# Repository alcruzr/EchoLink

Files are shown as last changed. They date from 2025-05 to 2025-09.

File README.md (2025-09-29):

# Overview

The EchoLink is a LoRa device that is able to send off-grid type messages when paired with a bluetooth enabled smartphone. The firmware aspect of the Echolink utilizes Meshtastic, an open source firmware. The hardware aspect of the EchoLink is a custom designed PCB that was created for a small and portable form factor.  A custom designed 3D printed enclosure provides easy access to user buttons/switches while also providing protection to the internal PCB and battery.

overall_cropped

# Specifications
* LoRa Transceiver: Waveshare Core 1262 HF LoRa Module, SX1262 Chip
* LoRa Antenna: SMA
* LoRa Operation Frequency: 915MHz (US)
* MCU: ESP32-S3-WROOM-1-MCN16R8
* Bluetooth v5.0
* USB Connector: USB-Micro B (for programming and power)
* Battery: 3.7V Li-Poly, 1200mAh
* Battery Charger: Input 5V via USB-Micro B. 500mAh Charge rate.
* Screen: 128x64 OLED Module, 
* GPS: Adafruit Industries ULTIMATE GPS MODULE PA1616D - 66 (integrated antenna)

# Firmware

The Echolink uses the Meshtastic open source firmware. The custom variant used for the EchoLink and its hardware is provided. The latest Meshtastic firmware will have to be downloaded from https://github.com/meshtastic/firmware 
The "echolink" variant will have to be copied into the /variants/esp32s3 folder. When compiling the firmware using VSCode, select the "echolink" environment. 

Detailed instructions on how to customize, compile, and upload the Meashtastic firmware can be found on the official Meshtastic website.  https://meshtastic.org/docs/development/firmware/build/

Once the firmware is uploaded to the Echolink and powered ON, please refer to the Meshtastic open source project website for further details and instructions on how to pair and operate with a bluetooth enabled smartphone device.  
https://meshtastic.org/

# Hardware

pcb label_final

The EchoLink is utilizes an ESP32-S3 microcontroller which has integrated wifi and bluetooth connectivity. The small form factor, along with its integrated antenna, also helped minimize the overall size of the EchoLink. The ESP32-S3 was also chosen because of the wide support within the Meshtastic firmware.

The LoRa transceiver comes with an on-board uFL connector. A uFL to SMA connector is used to extend the antenna port from the LoRa module to the top of the case allowing for easy access to the LoRa radio antenna port. 

The GPS module has a dedicated ON/OFF switch to allow for easy toggle of the GPS.

A 3.7V Li-Poly battery is used to supply power to the EchoLink. (NOTE: when selecting battery, make sure to verify polarity of JST connector.)

jst polarity new_final

The power circuit utilizes a linear voltage regulator with a fixed output voltage of 3.3V to power all components. To manage the power path between the battery input and USB-Micro B 5V input, a MOSFET power management circuit was implemented. This approach will allow the Echolink to be powered via the internal battery or external 5V input (for charging or power) automatically. 


There is also an available grove connector which allows for external I2C accessories to be connected.

# Case

The case was designed in Fusion360 and 3D printed using PLA. The simple design of the case allowed for minimal parts and hardware while also allowing access to all user buttons, switches and connections. The case consists of a main body, top cover, and single push button. A single M3x6x5 heat-pressed threaded insert and one M3x20 screw holds the entire case together. If the Grove connector is used, the battery will have to be installed at an angle to avoid interfering with the connector.

NOTE: The current case dimensions and design can only accomodate the 1200mAh 3.7V Li-Poly battery from Adafruit (https://www.adafruit.com/product/258). If using a different battery, please verify that dimensions are similar. 

case-bodyTop_label_final

# Resources

https://www.youtube.com/watch?v=zeSlRvCd6tg

https://meshtastic.org/

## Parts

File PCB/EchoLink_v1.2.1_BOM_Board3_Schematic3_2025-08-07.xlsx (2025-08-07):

No. | Quantity | Designator | Value | Part Number | Footprint | Comment
1 | 1 | BT1 |  |  | BAT-SMD_1042P | 1042P
2 | 1 | C1 | 10uF |  | C1206 | C1206
3 | 1 | C2 | 0.1uF |  | C1206 | C1206
4 | 1 | C3 | 10uF |  | C1206 | C1206
5 | 1 | C4 | 1uF |  | C1206 | C1206
6 | 1 | C6 | 1uF |  | C1206 | C1206
7 | 1 | C7 | 0.1uF |  | C1206 | C1206
8 | 1 | C8 | 0.1uF |  | C1206 | C1206
9 | 1 | C9 | 1uF |  | C1206 | C1206
10 | 1 | C10 | 1uF |  | C1206 | C1206
11 | 1 | C11 | 4.7uF |  | C1206 | C1206
12 | 1 | C12 | 4.7uF |  | C1206 | C1206
13 | 1 | D1 |  | STPS1L30U | SMB_L4.3-W3.6-LS5.4-RD | STPS1L30U
14 | 1 | D3 | Yellow | APTR3216SYCK | LED-SMD_L3.2-W1.6-R-RD | GPS Fix
15 | 1 | D4 | Red | APTR3216SURCK | LED-SMD_L3.2-W1.6-R-RD | Mesh Power
16 | 1 | D5 | Green | APTR3216CGCK | LED-SMD_L3.2-W1.6-R-RD | Message
17 | 1 | D6 |  | STPS1L30U | SMB_L4.3-W3.6-LS5.4-RD | STPS1L30U
18 | 1 | D7 | Red | APTR3216SURCK | LED-SMD_L3.2-W1.6-R-RD | charging
19 | 1 | D8 | Green | APTR3216CGCK | LED-SMD_L3.2-W1.6-R-RD | done charging
20 | 1 | JP9 |  |  | JUMPER_SOLDER_1X2 | GPS 1PPS
21 | 1 | JP19 |  |  | JUMPER_SOLDER_1X2 | Charge Enable
22 | 1 | P3 | JST | S2B-PH-SM4-TB | JST_S2B-PH-SM4-TB | 2 Pin JST Connector SMD
23 | 1 | PB1 |  | PTS636 SM43 SMTR LFS | PTS636 SM43 SMTR LFS | Boot
24 | 1 | PB2 |  | PTS636 SM43 SMTR LFS | PTS636 SM43 SMTR LFS | Reset
25 | 1 | PB3 |  | PTS636 SM43 SMTR LFS | PTS636 SM43 SMTR LFS | User Button
26 | 1 | Q1 |  | NTA4151PT1G | SOT-416_L1.6-W0.8-P1.00-LS1.6-BR | Power Path MOSFET
27 | 1 | R1 | 10K |  | R1206 | 1206_C
28 | 1 | R2 | 600Ω |  | R1206 | 1206_C
29 | 1 | R3 | 600Ω |  | R1206 | 1206_C
30 | 1 | R4 | 600Ω |  | R1206 | 1206_C
31 | 1 | R5 | 2kΩ |  | R1206 | 1206_C
32 | 1 | R6 | 5.1kΩ |  | R1206 | 1206_C
33 | 1 | R7 | 470Ω |  | R1206 | 1206_C
34 | 1 | R8 | 470Ω |  | R1206 | 1206_C
35 | 1 | SW1 |  | EG1257 | SW-SMD_EG1257 | GPS Power
36 | 1 | SW2 |  | EG1257 | SW-SMD_EG1257 | Main Power
37 | 1 | U1 |  | ESP32-S3-WROOM-1-N4 | WIFIM-SMD_ESP32-S3-WROOM-1-N8 | ESP32-S3-WROOM-1-N4
38 | 1 | U2 |  | XC6203P332PR-G | SOT-89-3_L4.5-W2.5-P1.50-LS4.2-BR | 3.3V Regulator
39 | 1 | U5 |  |  | OLED | Generic 128x64 I2C OLED Module
40 | 1 | U6 |  | 5186 | FGPMMOPA6H | GPS
41 | 1 | U8 |  | LR62E | LR62E | LoRa Radio IC
42 | 1 | U10 |  | CONUFL001-SMD-T | LINX_CONUFL001-SMD-T | Optional GPS antenna port connector
43 | 1 | U11 |  | MCP73831T-2ACI/OT | SOT-23-5_L2.9-W1.6-P0.95-LS2.8-BR | LiPo Charger controller
44 | 1 | U12 |  | Core1262-HF | Waveshare Core1262 SMD | LoRa Module
45 | 1 | USB1 |  | 10118193-0001LF | MICRO-USB-SMD_10118193-0001LF | Micro-USB

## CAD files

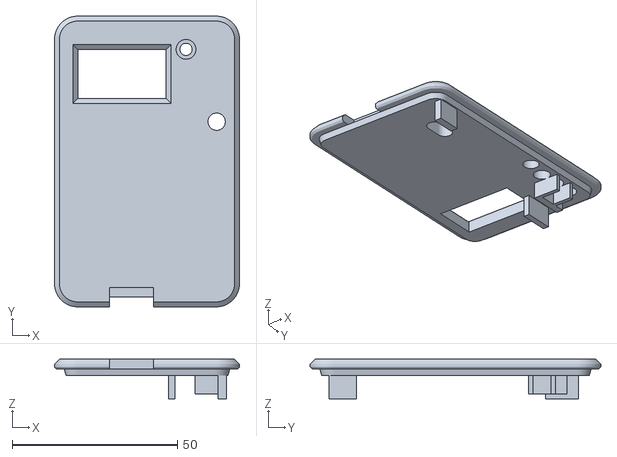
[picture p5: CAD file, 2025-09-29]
Case/EchoLinkv1.3_Case-Top.stl
56.0 x 88.0 x 12.0

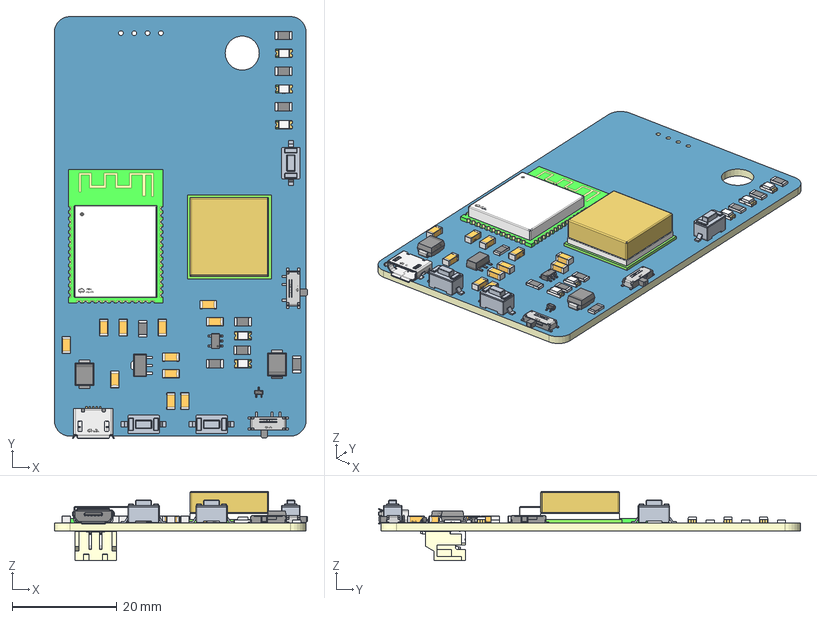
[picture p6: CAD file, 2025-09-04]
PCB/EchoLink_v1.2.1_3D_PCB3_2025-05-11.step
48.3 x 80.4 x 13.2 mm
Kc0X-TopTrack
Kc0X-BottomTrack
Kc0X-Board
Kc0X-Top FPC Stiffener
Kc0X-Bot FPC Stiffener
Kc0X-U2-SOT-89-3_L4.5-W2.5-P1.50-LS4.2-BR
Kc0X-D1-SMB_L4.3-W3.6-LS5.4-RD x 2
Kc0X-U1-wifim-smd_esp32-s3-wroom-1-n8
Kc0X-USB1-MICRO-USB-SMD_10118193-0001LF
Kc0X-C1-C1206 x 11

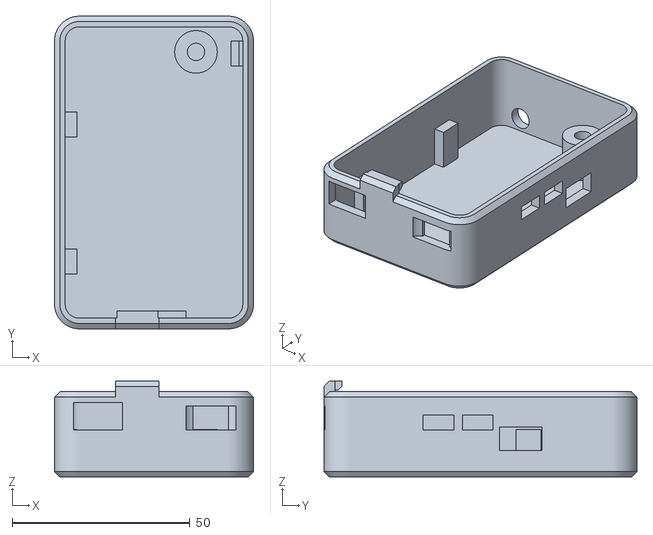
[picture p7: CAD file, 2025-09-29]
Case/EchoLinkv1.3_Case-Body.stl
56.0 x 88.0 x 27.0

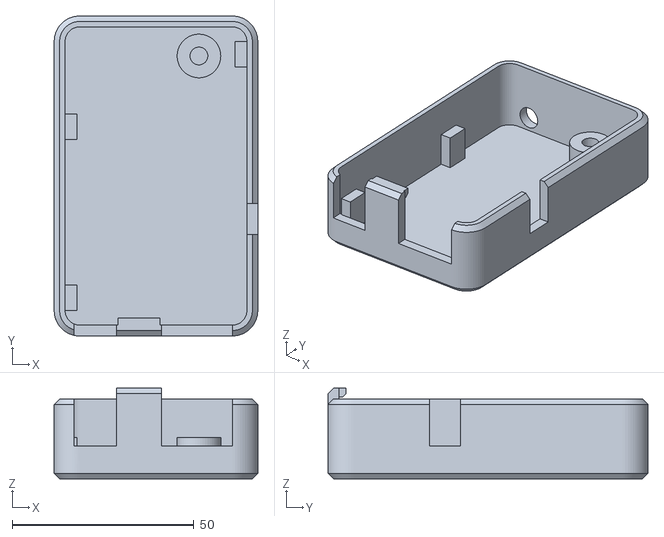
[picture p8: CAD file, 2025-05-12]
Case/EchoLinkv1.2_Case_v2.0-Body.stl
56.0 x 88.0 x 25.0

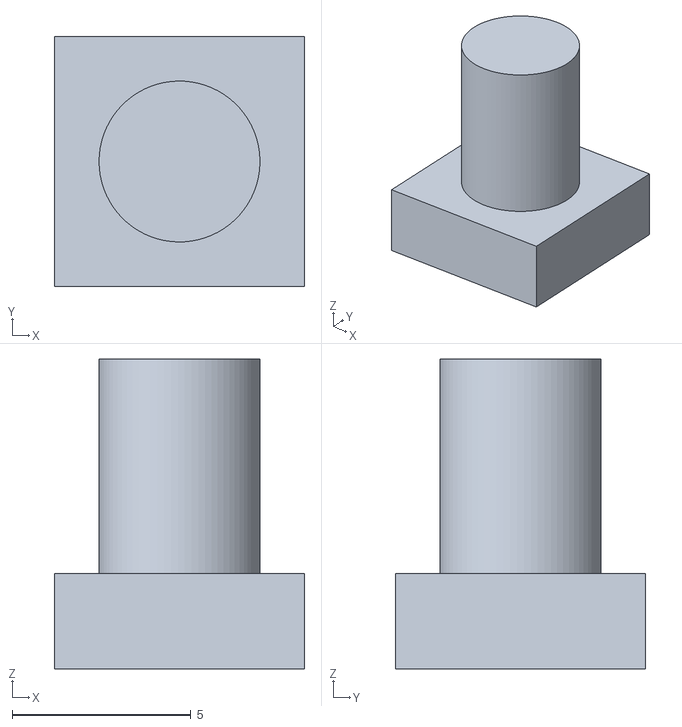
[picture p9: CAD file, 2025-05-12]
Case/EchoLinkv1.3_Case-Button.stl
7.00 x 7.00 x 8.67

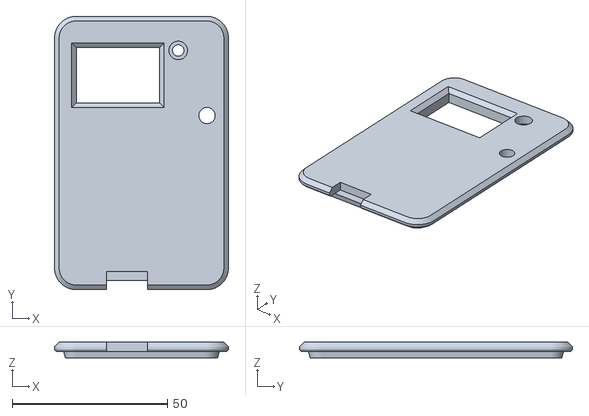
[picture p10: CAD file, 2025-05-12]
Case/EchoLinkv1.2_Case_v2.0-Top.stl
56.0 x 88.0 x 5.00

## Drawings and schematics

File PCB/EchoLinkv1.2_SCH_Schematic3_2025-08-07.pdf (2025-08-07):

IO12 20 IO13 21 IO14 22 IO21 23 IO47 24 IO48 25 IO45 26 IO0 27 IO35 28 IO36 29 IO37 30 IO38 31 IO39 32 IO40 33 IO41 34 IO42 35 RXD0 36 TXD0 37 IO2 38 IO1 39 GND 40 GND ⁴¹

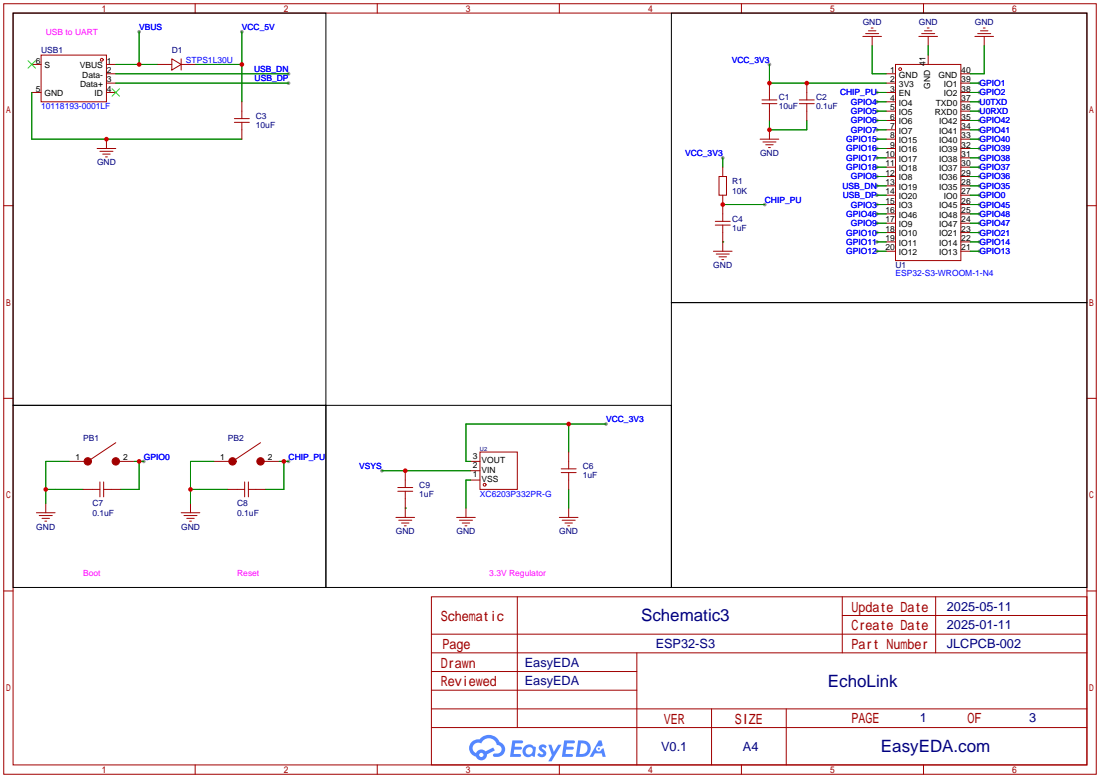
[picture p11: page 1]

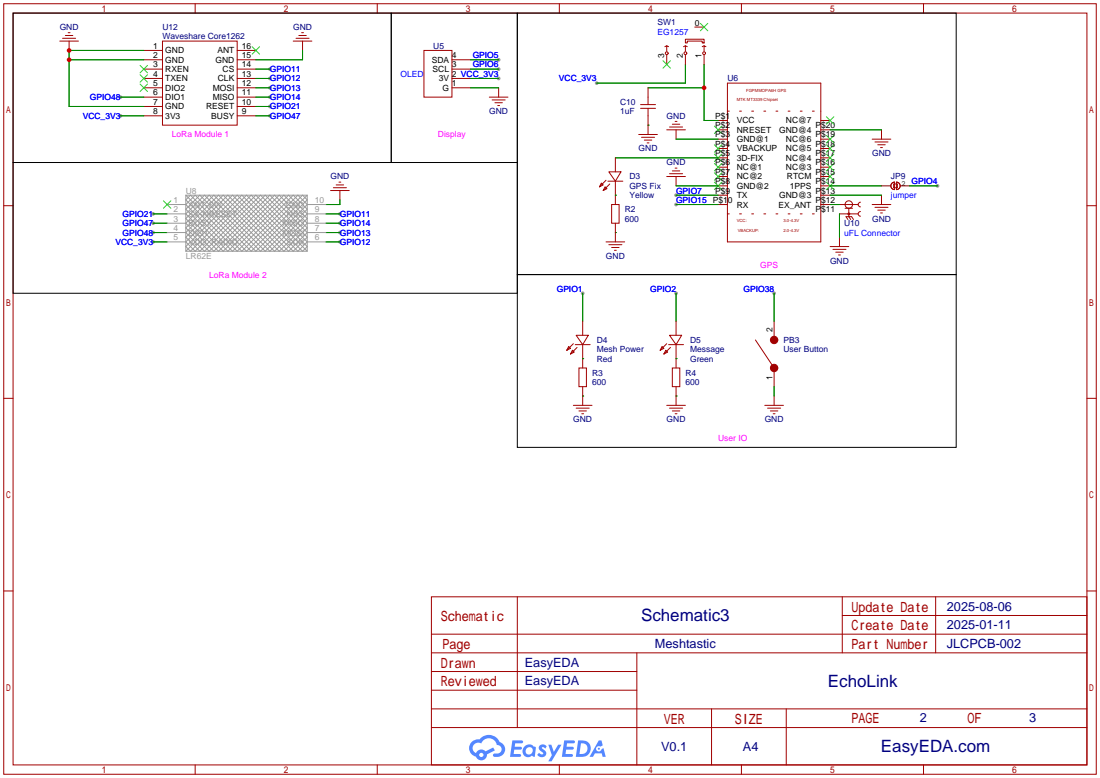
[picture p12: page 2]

RESET 10 MISO 11 MOSI 12 CLK 13 CS 14 GND 15 ANT 16

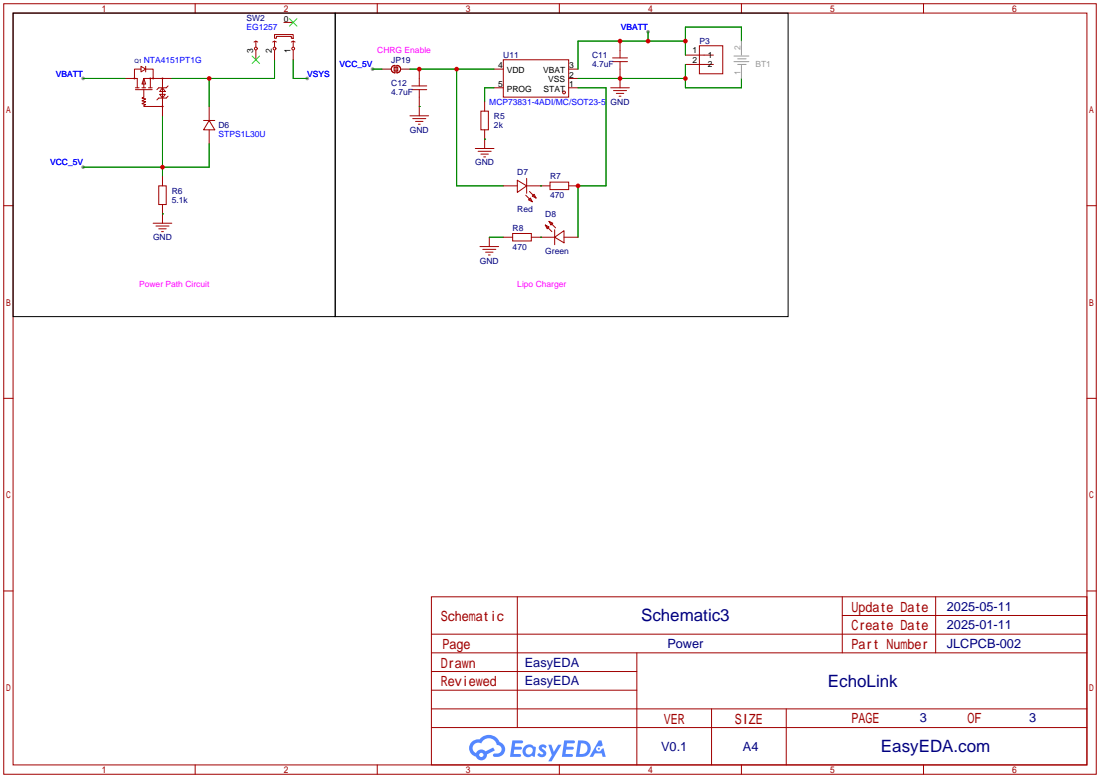
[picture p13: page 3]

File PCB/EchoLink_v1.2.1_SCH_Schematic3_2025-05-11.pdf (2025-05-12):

IO12 20 IO13 21 IO14 22 IO21 23 IO47 24 IO48 25 IO45 26 IO0 27 IO35 28 IO36 29 IO37 30 IO38 31 IO39 32 IO40 33 IO41 34 IO42 35 RXD0 36 TXD0 37 IO2 38 IO1 39 GND 40 GND ⁴¹

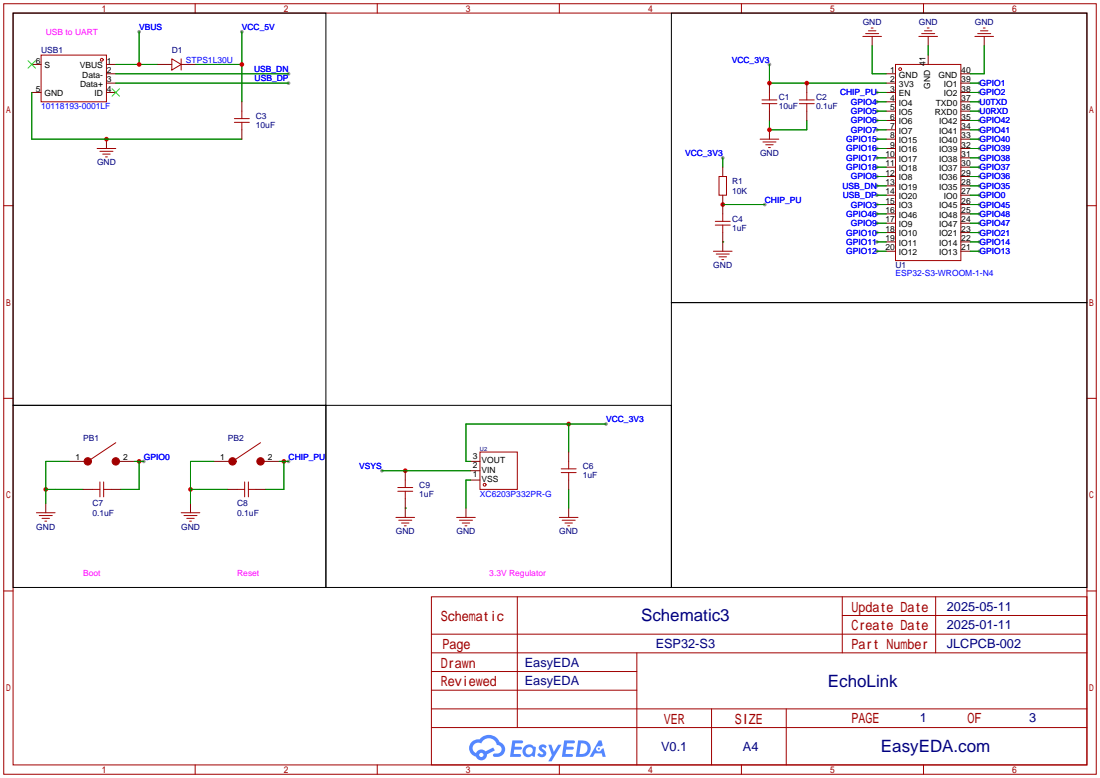
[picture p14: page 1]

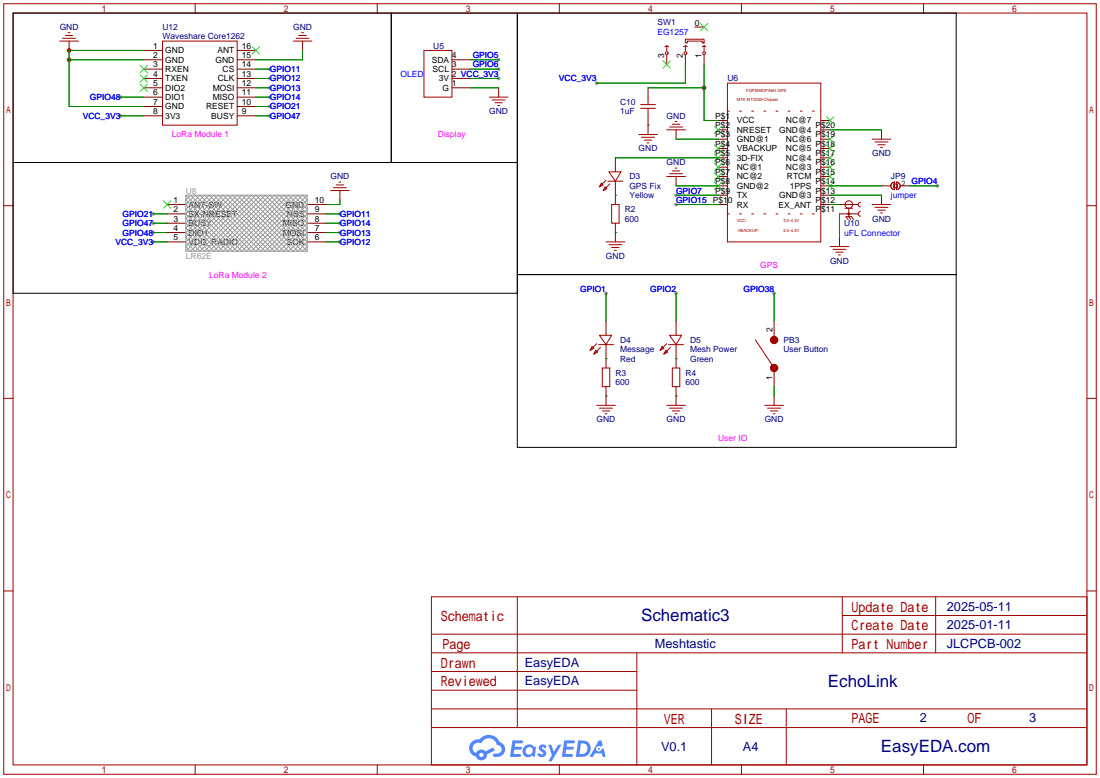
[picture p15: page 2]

RESET 10 MISO 11 MOSI 12 CLK 13 CS 14 GND 15 ANT 16

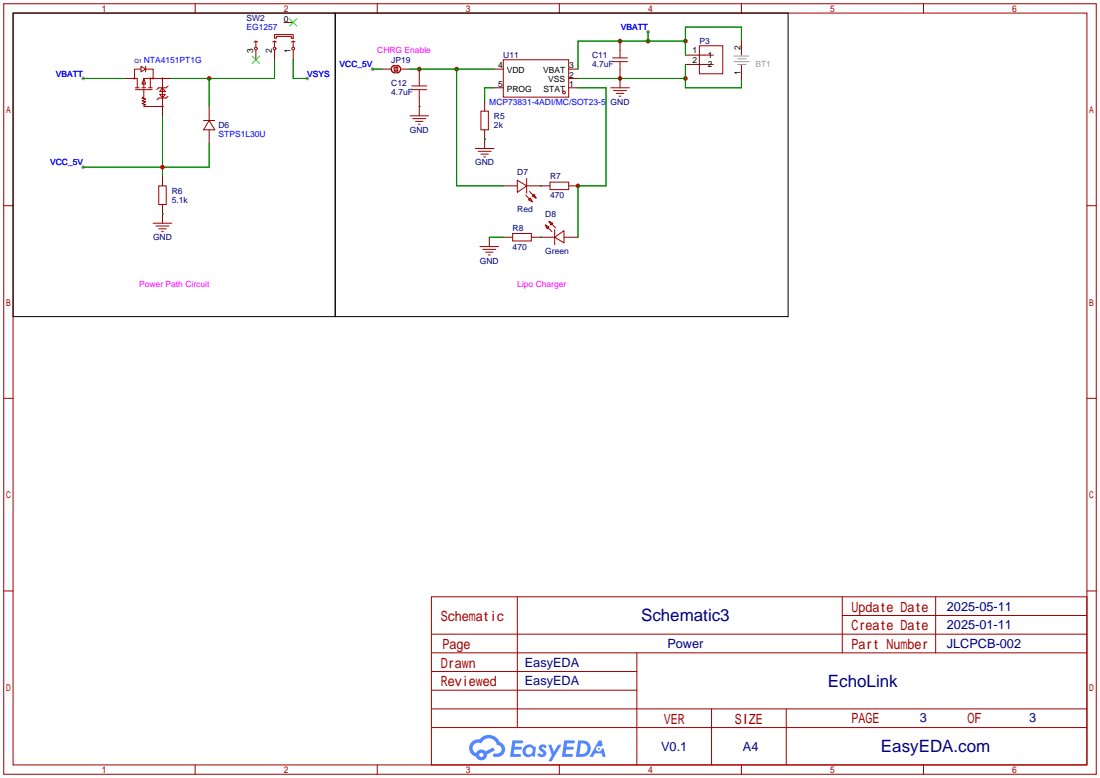
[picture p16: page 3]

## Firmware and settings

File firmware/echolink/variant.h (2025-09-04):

/*
Board Information: https://wiki.uniteng.com/en/meshtastic/station-g2
*/

// Station G2 may not have GPS installed, but it has a GROVE GPS Socket for Optional GPS Module
#define GPS_RX_PIN 7
#define GPS_TX_PIN 15
#define PIN_GPS_EN 16
#define GPS_EN_ACTIVE 1

// Station G2 has 1.3 inch OLED Screen
#define USE_SSD1306

#define I2C_SDA 5 // I2C pins for this board
#define I2C_SCL 6

#define BUTTON_PIN 38 // This is the Program Button
#define BUTTON_NEED_PULLUP

#define LED_PIN 1           // add status LED (heartbeat sequence to show device is powered)

#define EXT_NOTIFY_OUT 2  //LED GPIO pin for message notification

#define USE_SX1262

#define LORA_MISO 14 //14
#define LORA_SCK 12 //12
#define LORA_MOSI 13 //13
#define LORA_CS 11 //11

#define LORA_RESET 21 //21
#define LORA_DIO1 48 //48

#ifdef USE_SX1262
#define SX126X_CS LORA_CS // FIXME - we really should define LORA_CS instead
#define SX126X_DIO1 LORA_DIO1
#define SX126X_BUSY 47
#define SX126X_RESET LORA_RESET

//  DIO2 controlls an antenna switch and the TCXO voltage is controlled by DIO3
#define SX126X_DIO2_AS_RF_SWITCH
#define SX126X_DIO3_TCXO_VOLTAGE 1.8

// Ensure the PA does not exceed the saturation output power. More
// Info:https://wiki.uniteng.com/en/meshtastic/station-g2#summary-for-lora-power-amplifier-conduction-test
#define SX126X_MAX_POWER 19
#endif

#define BATTERY_PIN 8 // A battery voltage measurement pin, voltage divider connected here to measure battery voltage
#define ADC_CHANNEL ADC1_GPIO8_CHANNEL
#define ADC_MULTIPLIER 2.0


/*
#define BATTERY_PIN 4 // A battery voltage measurement pin, voltage divider connected here to measure battery voltage
#define ADC_CHANNEL ADC1_GPIO4_CHANNEL
#define ADC_MULTIPLIER 4
#define BATTERY_SENSE_SAMPLES 15 // Set the number of samples, It has an effect of increasing sensitivity.
#define BAT_FULLVOLT 8400
#define BAT_EMPTYVOLT 5000
#define BAT_CHARGINGVOLT 8400
#define BAT_NOBATVOLT 4460
#define CELL_TYPE_LION // same curve for liion/lipo
#define NUM_CELLS 2
*/

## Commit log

2025-04-22 Initial upload
    [.isort.cfg, configuration.h, partition-table.csv]
2025-05-12 updated PCB and case files
    [EchoLink_v1.2.1_BOM_Board3_Schematic3_2025-05-11.xlsx, EchoLinkv1.2_Case_v2.0-Body.stl, EchoLinkv1.2_Case_v2.0-Button.stl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]
2025-07-30 uploaded latest stable firmware version
    [.isort.cfg, configuration.h, partition-table.csv]
2025-08-07 updated schematic and BOM
    swapped labeling for Meshtastic power and message LEDS
    [EchoLink_v1.2.1_BOM_Board3_Schematic3_2025-05-11.xlsx, EchoLink_v1.2.1_BOM_Board3_Schematic3_2025-08-07.xlsx]
2025-09-04 v1.3 update
    [.isort.cfg, EchoLink_v1.2.1_3D_PCB3_2025-05-11.step, EchoLink_v1.2.1_BOM_Board3_Schematic3_2025-08-07.xlsx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]
2025-09-04 Revert "updated"
    This reverts commit 254d0d346a26a6f8f26897930eeeec9a6ade924f.
    [variant.h]
2025-09-04 update case
    [EchoLinkv1.3_Case-Body.stl, EchoLinkv1.3_Case-Button.stl, EchoLinkv1.3_Case-Top.stl]
2025-09-29 removed full firmware
    [.isort.cfg, configuration.h, partition-table.csv]
